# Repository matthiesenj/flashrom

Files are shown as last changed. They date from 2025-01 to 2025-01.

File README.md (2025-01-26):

# Flashrom
The main purpose of this project is to implement a flashmemory-based kickstart ROM substitute/switcher for the Commodore Amiga line of computers.
It may also serve as a general-purpose substitute for 27Cx00 compatible JEDEC pinout (EP)ROMs.

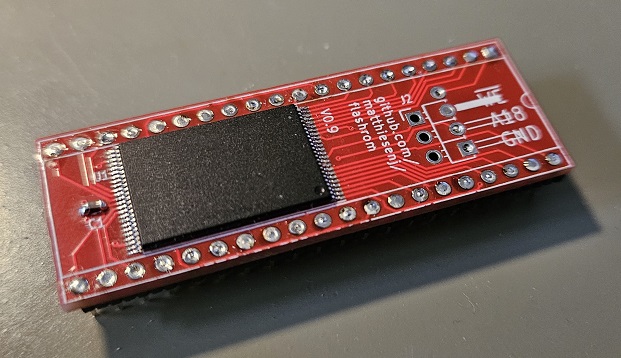
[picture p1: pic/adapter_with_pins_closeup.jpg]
flash adapter


It is based around the 29F800 1MB flash memory chip and is very close to the same dimensions as a 40 pin DIP socket, and low profile.

## Disclaimer!
This is a homebrew project - I provide absolutely no warranties or promises about the suitability of this for you or your hardware - if something breaks, it's on yourself!

## Features
- 1MB flash-based programmable (EP)ROM replacement
- About the same size as a 40-pin DIP socket, so fits side by side in Amiga 4000
- Divisible into two or four ROM sections, switchable using regular toggle switch
- Pairable switching for systems using two ROMs, for example Amiga 1200 and 4000
- Slim pins to avoid damage to DIP socket wipes
- Compatibility mode for Amiga 500 rev 3-5, which have two signals swapped in the socket

## Inspiration
There are some other projects out there which are similar to this one, and while I probably can't guarantee that there was no inspirational effects at all from these, all of the electrical design, schematics and PCB layouts in this project were done completely from scratch.

## Compatibility
I've only tested this with Amiga 4000 and Amiga 500, as it's all I have access to, but as the pinout matches 27C400 there's no reason it shouldn't work in other 5V systems using this pinout.
Jumpers provide compatibility with Amiga 500 rev 3 and 5 which has two ROM socket pins swapped (other revs affected?).

## Important!
- Be careful about electrostatic discharge when handling - signals that go to an optional ROM switch have provisions for in-circuit ESD protection
- When using in a 42-pin socket (for 27C160 JEDEC pinout), make sure the board is inserted in socket positions 2-41 - do *not* insert into position 1!
- Make sure not to insert board backwards - the notch marking should match the notch of the socket

## Versatility

## Socket preservation
Dual-wipe DIP sockets will get damaged by inserting a regular pin strip with 0.6 x 0.6 mm square pins into it - or, it's actually when you need to insert a 40 pin DIP chip again, it will cause problems, because the wide pins of the pin strip bends the wipes so they don't spring back properly (a regular DIP chip has about 0.25mm wide pins).

This project is intended to use 1.27mm pin strips with every other pin removed. These can be found with 0.4 x 0.4mm (or slimmer) pins which won't damage the dual-wipe socket.
Because of this, the PCB holes for the pins are smaller to correctly align the strips while being soldered.

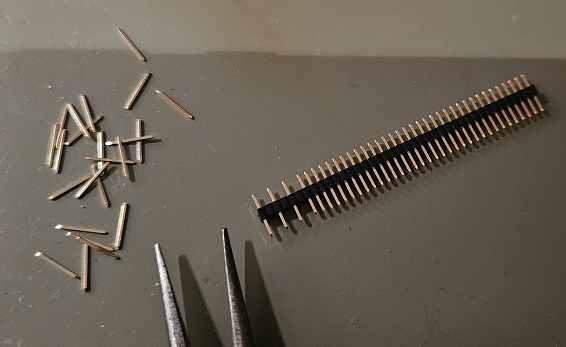
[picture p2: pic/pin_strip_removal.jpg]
pin removal


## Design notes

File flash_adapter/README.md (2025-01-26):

# TL866CS/A flash adapter for 29Fx00 flashrom project

This PCBA makes it possible to use a TL866 programmer with the TSOP48/SOP44 adapter to program the 29Fx00 flashrom solution.
It's also useful for reading the contents of EPROMs and mask ROMs with a JEDEC pinout matching an Amiga ROM or 27Cx00 EPROM.

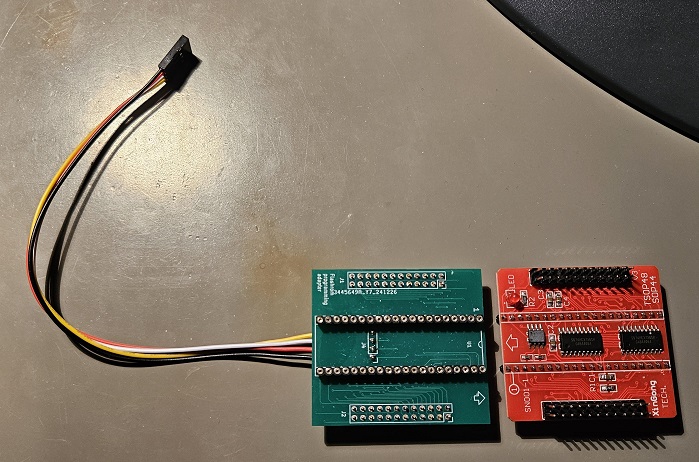
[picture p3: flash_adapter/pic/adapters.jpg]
TL866 adapter front
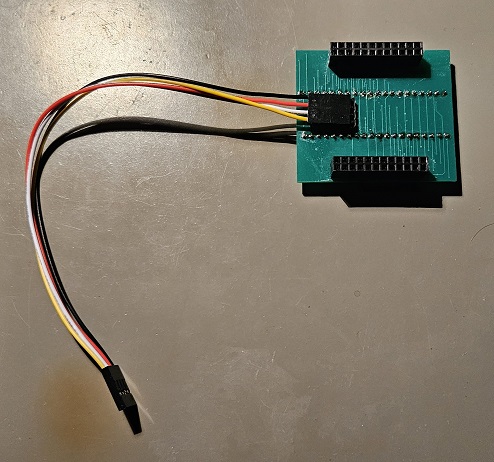
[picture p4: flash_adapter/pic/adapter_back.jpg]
TL866 adapter back
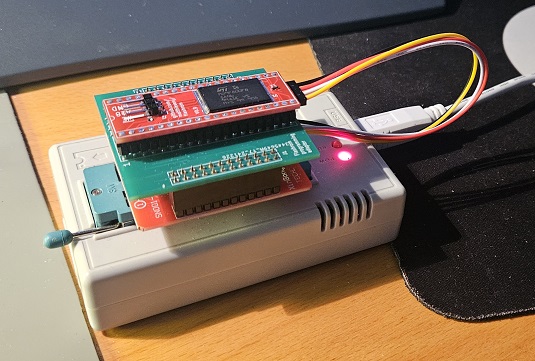
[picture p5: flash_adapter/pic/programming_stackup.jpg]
programming stackup
  

The design is very simple, it just reroutes the signals of the TSOP/SOP adapter to match the pinout of mentioned ROMs/EPROMs.
Only a few headers need to be soldered to the board, and the through holes for the main socket are Ø 1.0mm to be able to fit a Textool ZIF socket if so desired.
The 4-wire cable serves to connect the 4 missing signals on the 40-pin DIP interface required for programming (_WE, RY_BY, A18, and _RESET) to the programming adapter

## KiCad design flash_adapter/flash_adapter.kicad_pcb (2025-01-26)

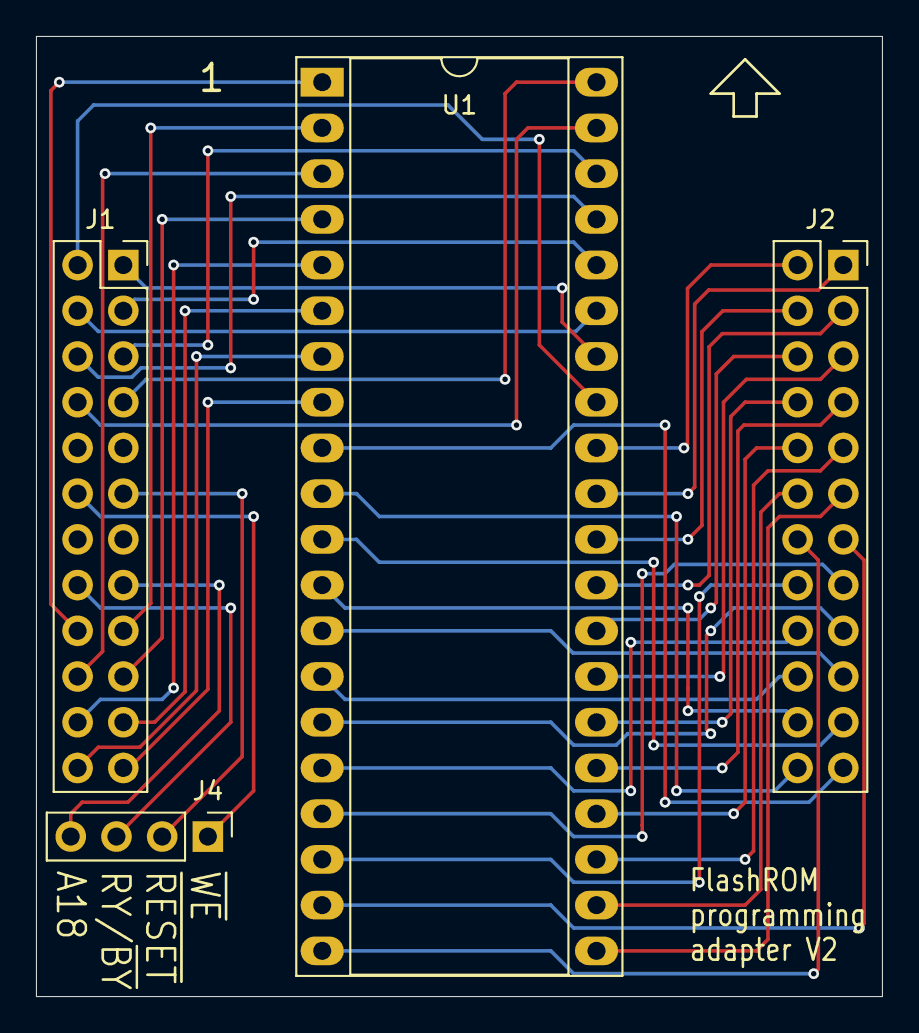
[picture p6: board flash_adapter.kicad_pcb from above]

Board: 2 copper layers, 47.0 x 53.3 mm, 4 parts (0 on the bottom side), 44 nets.

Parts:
J1, J2: Conn_02x12_Odd_Even; PinSocket_2x12_P2.54mm_Vertical
J4: Conn_01x04_Pin; PinHeader_1x04_P2.54mm_Vertical
U1: Kickstart_Socket_A4000; DIP-40_W15.24mm_Socket_LongPads

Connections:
/A18: J1.15, J4.4
/L1: J1.1, U1.34 (A14)
/L2: J1.2, U1.33 (A15)
/L3: J1.3, U1.36 (A12)
/L4: J1.4, U1.35 (A13)
/L5: J1.5, U1.38 (A10)
/L6: J1.6, U1.37 (A11)
/L7: J1.7, U1.40 (A8)
/L8: J1.8, U1.39 (A9)
/L11: J1.11, J4.2
/L12: J1.12, J4.1
/L16: J1.16, J4.3
/L17: J1.17, U1.2 (A7)
/L18: J1.18, U1.1 (A17)
/L19: J1.19, U1.4 (A5)
/L20: J1.20, U1.3 (A6)
/L21: J1.21, U1.6 (A3)
/L22: J1.22, U1.5 (A4)
/L23: J1.23, U1.8 (A1)
/L24: J1.24, U1.7 (A2)
/R1: J2.1, U1.31 (MODE)
/R2: J2.2, U1.32 (A16)
/R3: J2.3, U1.29 (D15)
/R4: J2.4, U1.30 (GND)
/R5: J2.5, U1.27 (D14)
/R6: J2.6, U1.28 (D7)
/R7: J2.7, U1.25 (D13)
/R8: J2.8, U1.26 (D6)
/R9: J2.9, U1.23 (D12)
/R10: J2.10, U1.24 (D5)
/R11: J2.11, U1.21 (VCC)
/R12: J2.12, U1.22 (D4)
/R13: J2.13, U1.19 (D3)
/R14: J2.14, U1.20 (D11)
/R15: J2.15, U1.17 (D2)
/R16: J2.16, U1.18 (D10)
/R17: J2.17, U1.15 (D1)
/R18: J2.18, U1.16 (D9)
/R19: J2.19, U1.13 (D0)
/R20: J2.20, U1.14 (D8)
/R21: J2.21, U1.11 (GND)
/R22: J2.22, U1.12 (~OE)
/R23: J2.23, U1.9 (A0)
/R24: J2.24, U1.10 (~CS)

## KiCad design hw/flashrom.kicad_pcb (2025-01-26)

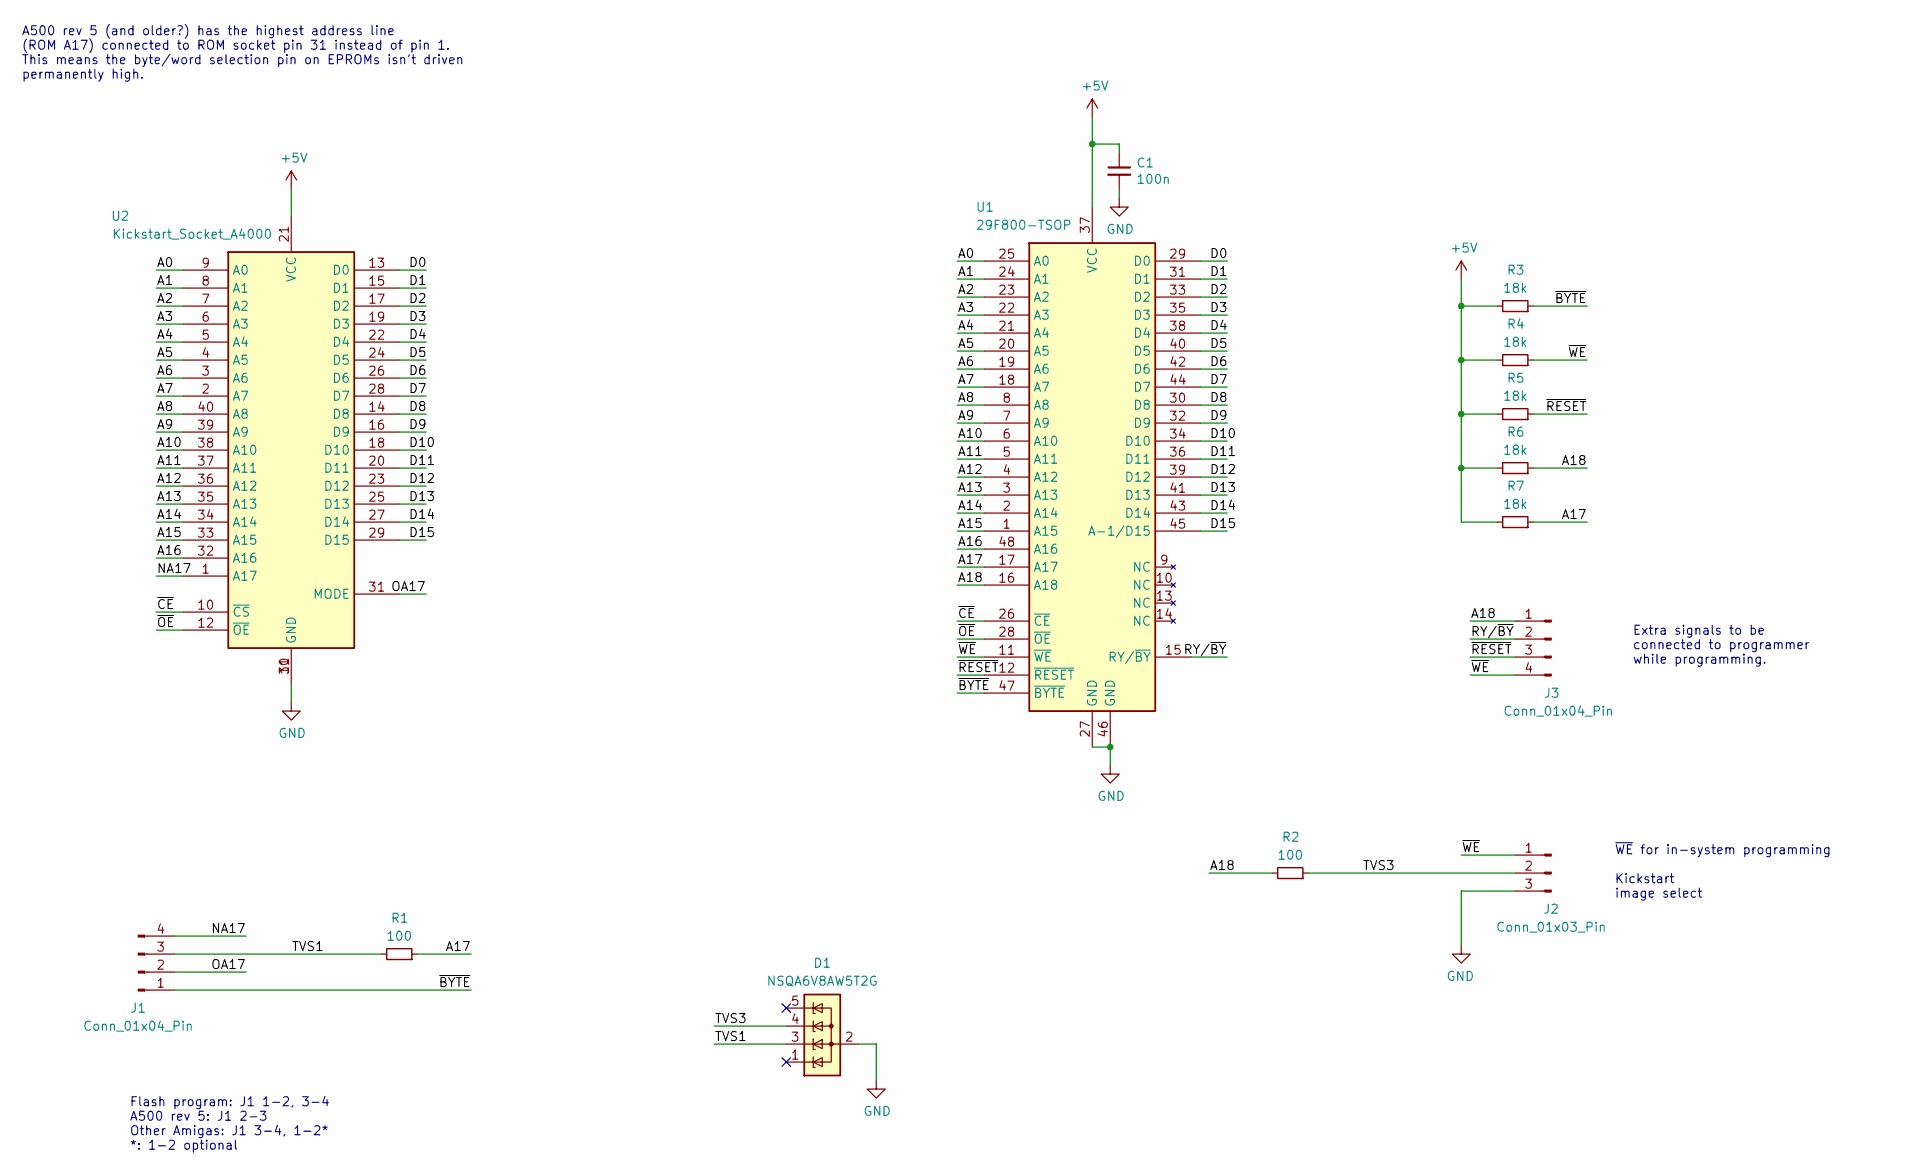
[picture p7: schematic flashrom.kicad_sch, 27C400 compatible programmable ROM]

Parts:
C1: 100n; C_0603_1608Metric
D1: NSQA6V8AW5T2G; SOT-353_SC-70-5
J1, J3: Conn_01x04_Pin; Harwin_M20-89004xx_1x04_P2.54mm_Horizontal
J2: Conn_01x03_Pin; Harwin_M20-89003xx_1x03_P2.54mm_Horizontal
R1, R2: 100; R_0603_1608Metric
R3, R4, R5, R6, R7: 18k; R_0603_1608Metric
U1: 29F800-TSOP; TSOP-I-48_18.4x12mm_P0.5mm
U2: Kickstart_Socket_A4000; DIP-40_W15.24mm_Socket

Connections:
+5V: C1.1, R3.2, R4.2, R5.2, R6.2, R7.2, U1.37 (VCC), U2.21 (VCC)
/A0: U1.25 (A0), U2.9 (A0)
/A1: U1.24 (A1), U2.8 (A1)
/A2: U1.23 (A2), U2.7 (A2)
/A3: U1.22 (A3), U2.6 (A3)
/A4: U1.21 (A4), U2.5 (A4)
/A5: U1.20 (A5), U2.4 (A5)
/A6: U1.19 (A6), U2.3 (A6)
/A7: U1.18 (A7), U2.2 (A7)
/A8: U1.8 (A8), U2.40 (A8)
/A9: U1.7 (A9), U2.39 (A9)
/A10: U1.6 (A10), U2.38 (A10)
/A11: U1.5 (A11), U2.37 (A11)
/A12: U1.4 (A12), U2.36 (A12)
/A13: U1.3 (A13), U2.35 (A13)
/A14: U1.2 (A14), U2.34 (A14)
/A15: U1.1 (A15), U2.33 (A15)
/A16: U1.48 (A16), U2.32 (A16)
/A17: R1.1, R7.1, U1.17 (A17)
/A18: J3.1, R2.2, R6.1, U1.16 (A18)
/D0: U1.29 (D0), U2.13 (D0)
/D1: U1.31 (D1), U2.15 (D1)
/D2: U1.33 (D2), U2.17 (D2)
/D3: U1.35 (D3), U2.19 (D3)
/D4: U1.38 (D4), U2.22 (D4)
/D5: U1.40 (D5), U2.24 (D5)
/D6: U1.42 (D6), U2.26 (D6)
/D7: U1.44 (D7), U2.28 (D7)
/D8: U1.30 (D8), U2.14 (D8)
/D9: U1.32 (D9), U2.16 (D9)
/D10: U1.34 (D10), U2.18 (D10)
/D11: U1.36 (D11), U2.20 (D11)
/D12: U1.39 (D12), U2.23 (D12)
/D13: U1.41 (D13), U2.25 (D13)
/D14: U1.43 (D14), U2.27 (D14)
/D15: U1.45 (A-1/D15), U2.29 (D15)
/NA17: J1.4, U2.1 (A17)
/OA17: J1.2, U2.31 (MODE)
/RY/~BY: J3.2, U1.15 (RY/~BY)
/TVS1: D1.3 (K), J1.3, R1.2
/TVS3: D1.4 (K), J2.2, R2.1
/~BYTE: J1.1, R3.1, U1.47 (~BYTE)
/~CE: U1.26 (~CE), U2.10 (~CS)
/~OE: U1.28 (~OE), U2.12 (~OE)
/~RESET: J3.3, R5.1, U1.12 (~RESET)
/~WE: J2.1, J3.4, R4.1, U1.11 (~WE)
GND: C1.2, D1.2 (A), J2.3, U1.27 (GND), U1.46 (GND), U2.11 (GND), U2.30 (GND)

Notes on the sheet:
A500 rev 5 (and older?) has the highest address line (ROM A17) connected to ROM socket pin 31 instead of pin 1. This means the byte/word selection pin on EPROMs isn't driven permanently high.
Flash program: J1 1-2, 3-4 A500 rev 5: J1 2-3 Other Amigas: J1 3-4, 1-2* *: 1-2 optional
Extra signals to be connected to programmer while programming.
~{WE} for in-system programming Kickstart image select

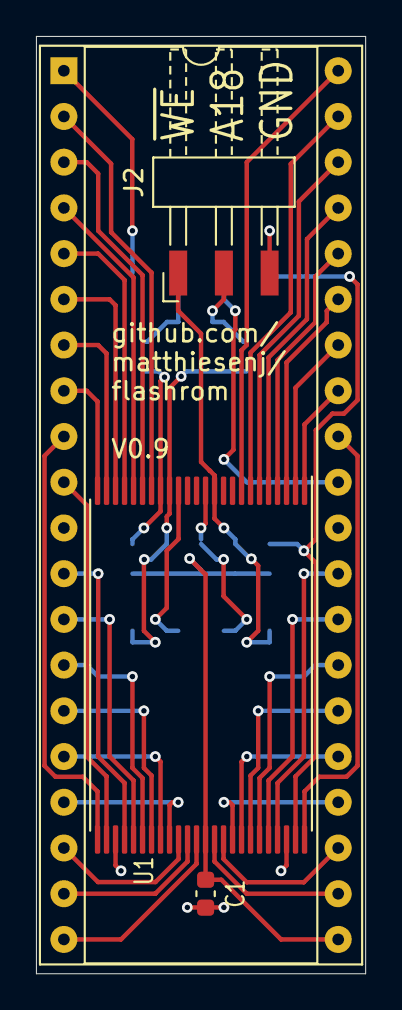
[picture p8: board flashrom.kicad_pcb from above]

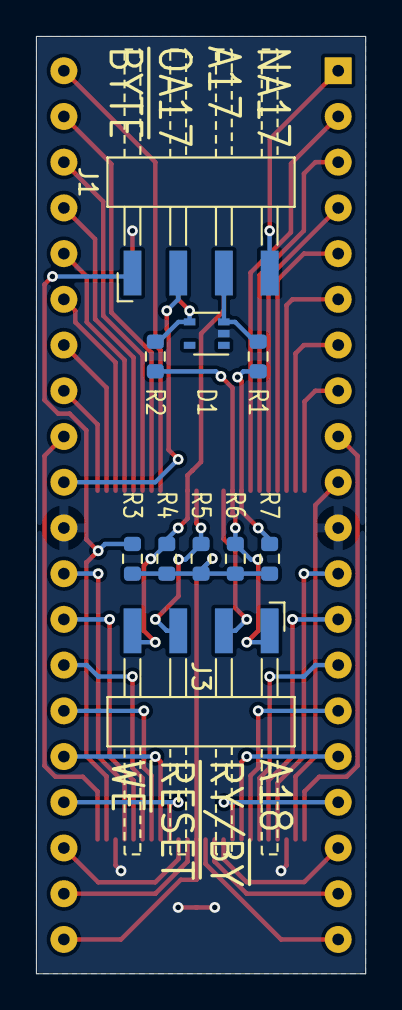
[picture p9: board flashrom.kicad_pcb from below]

Board: 2 copper layers, 18.3 x 52.1 mm, 14 parts (10 on the bottom side), 47 nets.

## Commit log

2020-11-02 move kicad project to hw dir
    [flashrom.kicad_pcb, flashrom.sch]
2024-12-13 convert project to kicad 7 format
    [flashrom.kicad_pcb, flashrom.kicad_sch, flashrom.sch]
2024-12-18 add a1200 kickstart socket symbol
2024-12-18 switch flash to tsop, add tvs, and route pcb
    [flashrom.kicad_pcb, flashrom.kicad_sch]
2024-12-19 initial commit of tl866 flash adapter files
    [flash_adapter.kicad_pcb, flash_adapter.kicad_sch]
2024-12-22 finish routing
    [flash_adapter.kicad_pcb]
2024-12-23 change pin 1 of j2 to /WE to support a wire for in-system programming
    [flashrom.kicad_pcb, flashrom.kicad_sch]
2024-12-23 move c1 to f.cu for lesser inductance
    [flashrom.kicad_pcb]
2024-12-23 update Ux footprints to match library
    [flashrom.kicad_pcb]
2024-12-23 set gerber and drill output options
    [flashrom.kicad_pcb]
2024-12-25 increase silkscreen line width; manufacturability
    [flash_adapter.kicad_pcb]
2024-12-25 change product text to github repo url
    [flashrom.kicad_pcb]
2024-12-28 add J4 silkscreen pin descriptions
    [flash_adapter.kicad_pcb]
2025-01-12 increase dip 40 socket hole size in order to allow use of textool socket
    [flash_adapter.kicad_pcb, flash_adapter.kicad_sch]
2025-01-12 update schematic legend
    [flash_adapter.kicad_sch]
2025-01-14 narrow pcb to 18.3mm width to fit a4000d
    [flashrom.kicad_pcb]
2025-01-14 switch j3 footprint to horizontal pin header
    [flashrom.kicad_pcb, flashrom.kicad_sch]
2025-01-15 switch j1 and j2 footprints to smd horizontal header
    [flashrom.kicad_pcb, flashrom.kicad_sch]
2025-01-15 use unfilled rectangle for pin header pin 1 silkscreen so not to cover up pin functions
    [flashrom.kicad_pcb]
2025-01-25 update graphics
    [flashrom.kicad_pcb]
2025-01-25 update text
    [flashrom.kicad_sch]
2025-01-26 increase pull-ups to 18k, the value actually used in the protos
    [flashrom.kicad_pcb, flashrom.kicad_sch]
2025-01-26 relocate header for non-socket signals to next to socket to avoid through holes under textool
    [flash_adapter.kicad_pcb, flash_adapter.kicad_sch]
